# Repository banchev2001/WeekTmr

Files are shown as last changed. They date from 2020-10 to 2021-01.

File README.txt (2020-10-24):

 Files description:
 ================================================================================
 * DS3231_datasheet.pdf - Data sheet of DS3231 RTCC
 * DS3231_Library_Documentation.pdf - Library documentation by Henning Karlsen
 * RTC_DS3231_LCD_Test.ino - Main source code of the project - using Arduino IDE
 * /libraries/DS3231 contain Henning Karlsen free library with examples
 * /libraries/WeekTimerLibrary/ contain Stoian Banchev library for WeekTimer object
 * /Board/WeekTmr contain cidKad project of the board and schematic 
 
 Board: Arduino nano
 
 Project Conception:
 ================================================================================
 The board have two timers with three layers. Each timer have output. Timer1 
 drives Output-1 (pin 14), Timer2 drives Output-2 (pin 15). Every lyer of timers 
 are connected in "OR" logic to output. Every layer have three settings "On time", "Off time" and 
 Day of week scheme.
 
 Logic Diagram:
 ================================================================================
 
 Timer1, Layer1 ---|
 Timer1, Layer2 ---|-|OR|-Output1 (pin 14)
 Timer1, Layer3 ---|
 
 Timer2, Layer1 ---|
 Timer2, Layer2 ---|-|OR|-Output2 (pin 15)
 Timer2, Layer3 ---|

 Timer settings:
 ==================================================================================
 Days: Days in week in wich timer work,  contain seven fields for every day of week.
 On Time: Hour and minutes of the day that timer start.
 Off Time: Hour and minutes of the day that timer stop.

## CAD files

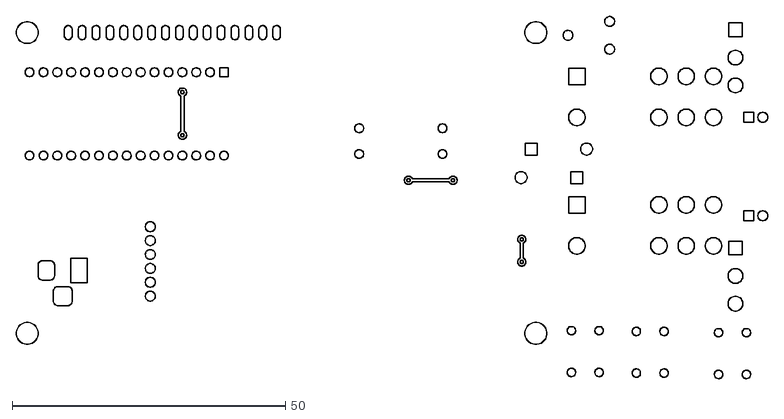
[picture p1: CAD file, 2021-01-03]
Board/WeekTmr/WeekTmr-F_Cu.dxf
137.4 x 66.2

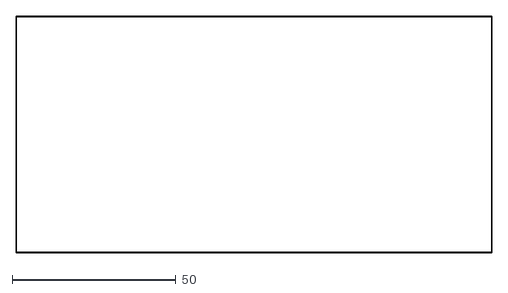
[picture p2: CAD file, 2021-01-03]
Board/WeekTmr/WeekTmr-Edge_Cuts.dxf
145.1 x 72.1

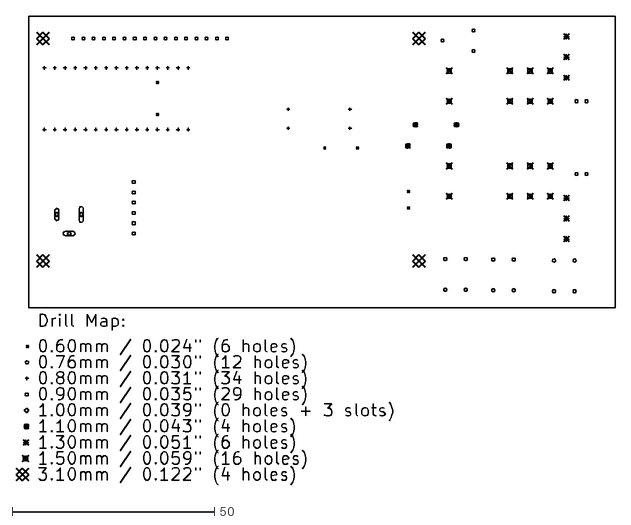
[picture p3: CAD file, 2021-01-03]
Board/WeekTmr/WeekTmr-PTH-drl_map.dxf
148.1 x 115.8

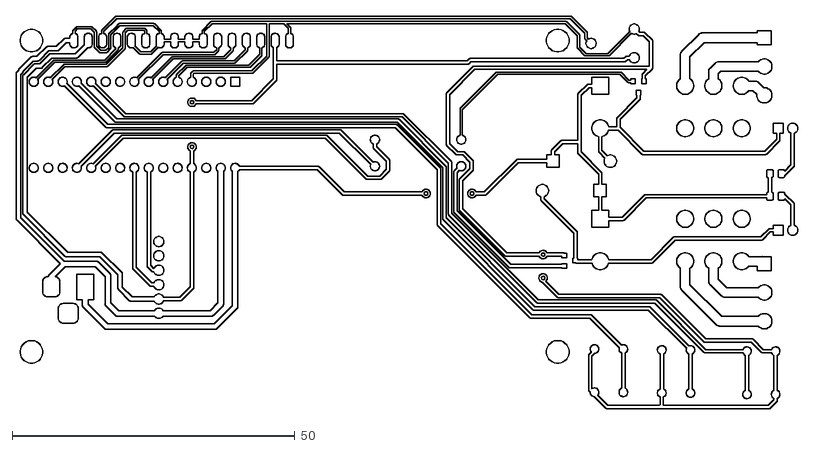
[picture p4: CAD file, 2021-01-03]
Board/WeekTmr/WeekTmr-B_Cu.dxf
138.1 x 69.3

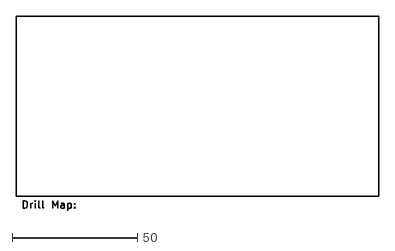
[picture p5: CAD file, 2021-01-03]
Board/WeekTmr/WeekTmr-NPTH-drl_map.dxf
145.0 x 77.7

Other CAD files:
Board/WeekTmr/WeekTmr-B_Mask.dxf
Board/WeekTmr/WeekTmr-B_Paste.dxf
Board/WeekTmr/WeekTmr-B_SilkS.dxf
Board/WeekTmr/WeekTmr-F_Mask.dxf
Board/WeekTmr/WeekTmr-F_Paste.dxf
Board/WeekTmr/WeekTmr-F_SilkS.dxf

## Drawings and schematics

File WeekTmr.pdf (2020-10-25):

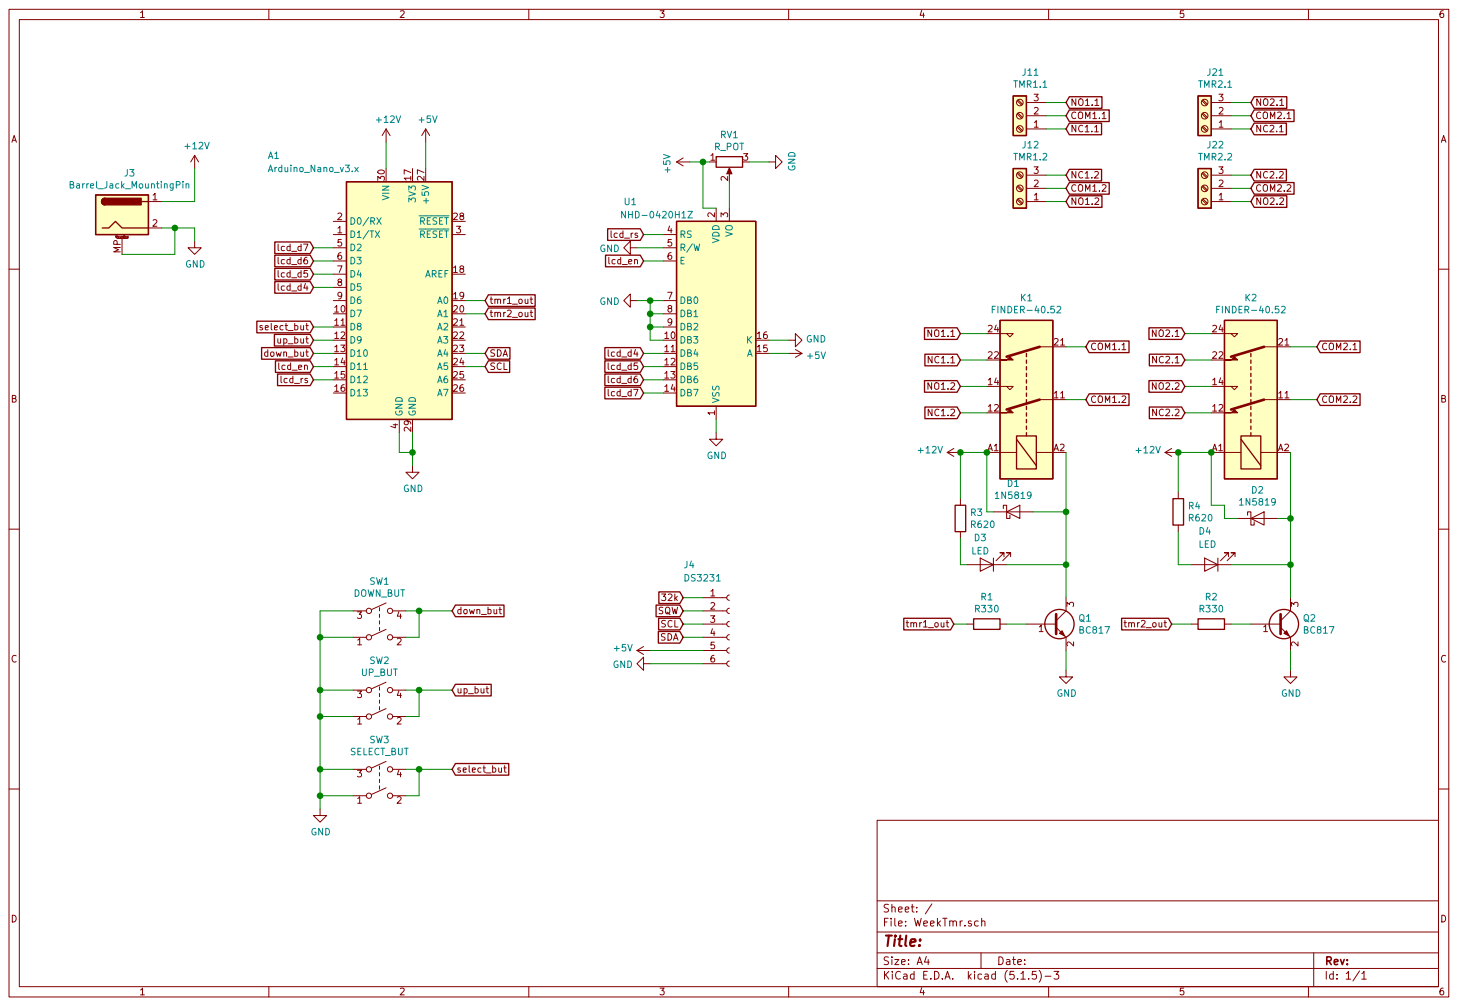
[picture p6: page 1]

Id: 1/1 Title: File: WeekTmr.sch Sheet: /

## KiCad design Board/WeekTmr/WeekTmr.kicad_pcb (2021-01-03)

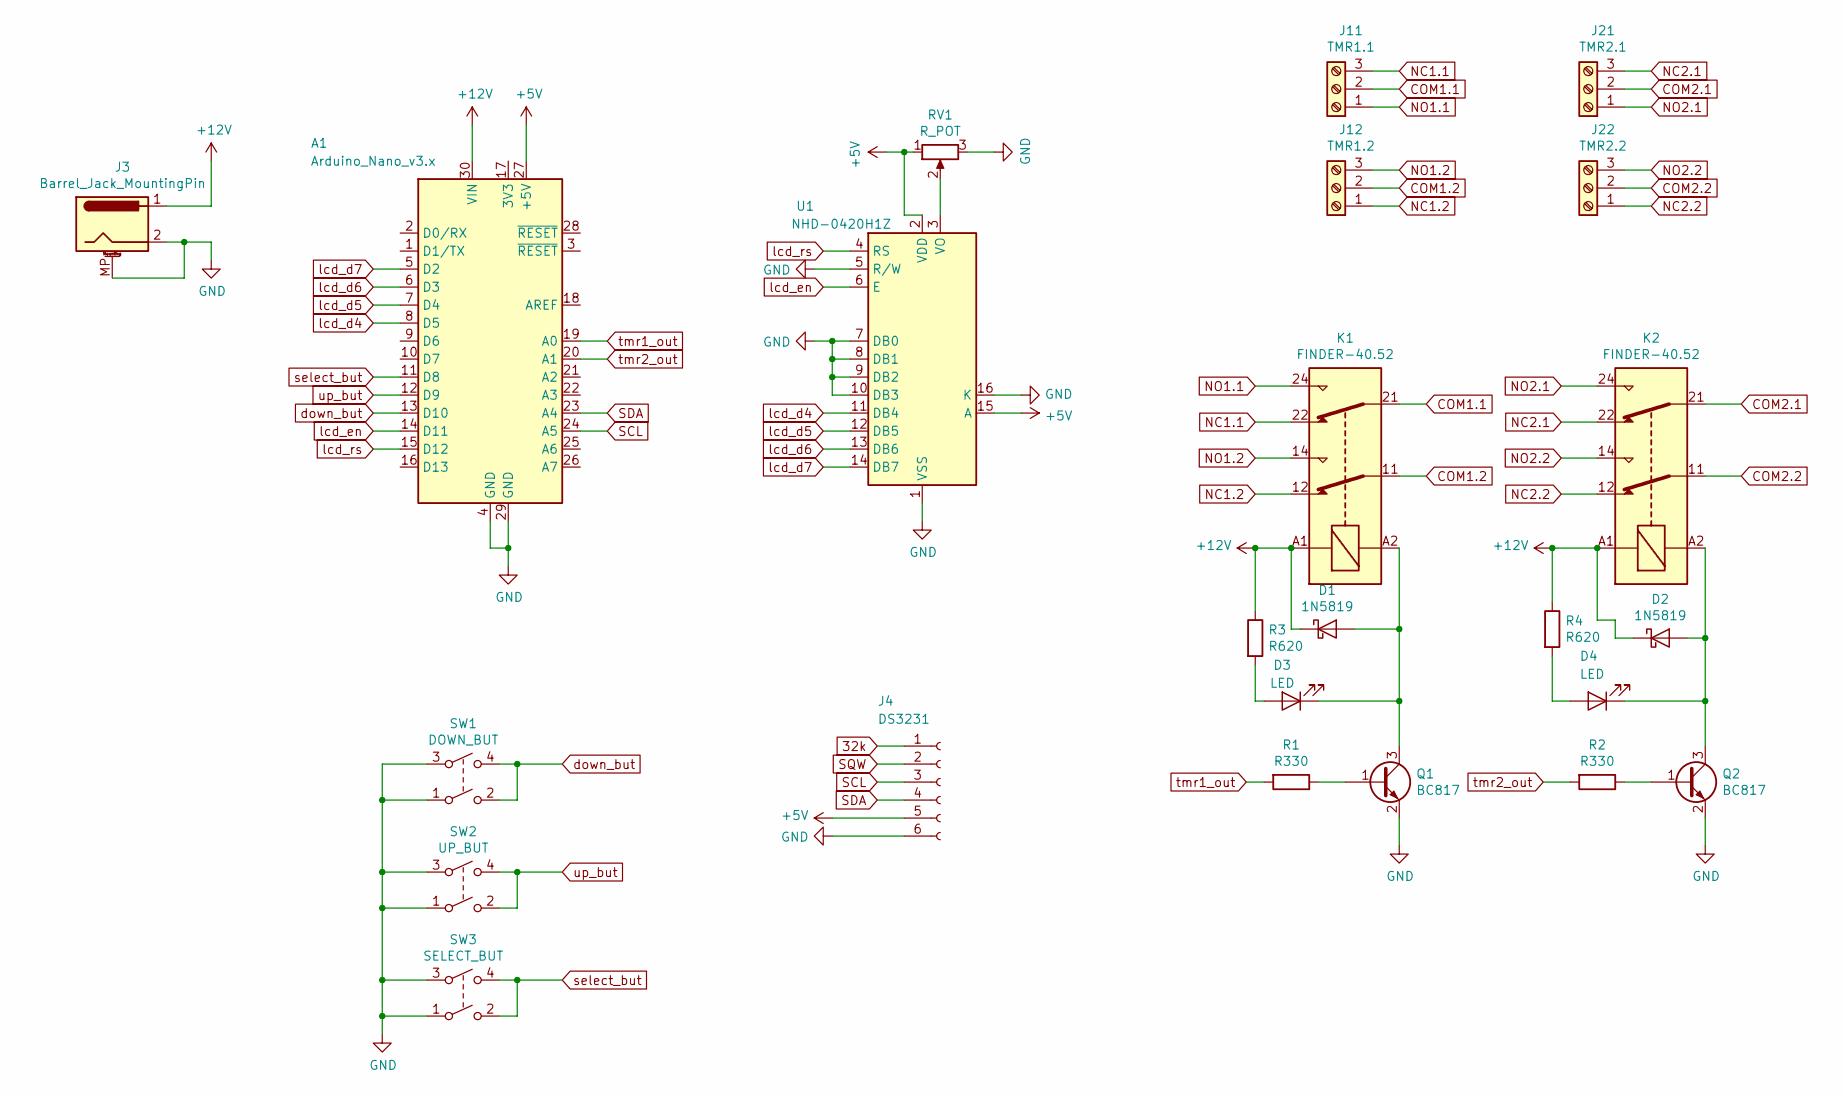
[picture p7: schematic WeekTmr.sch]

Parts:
A1: Arduino_Nano_v3.x; Arduino_Nano_direct_Slot
D1, D2: 1N5819; D_DO-41_SOD81_P10.16mm_Horizontal
D3, D4: LED; LED_D5.0mm_Clear
J3: Barrel_Jack_MountingPin; BarrelJack_Horizontal_comet
J4: DS3231; DS3231_RTC_Module
J11: TMR1.1; COMET_2EDGR-5.08-14-00AH
J12: TMR1.2; COMET_2EDGR-5.08-14-00AH
J21: TMR2.1; COMET_2EDGR-5.08-14-00AH
J22: TMR2.2; COMET_2EDGR-5.08-14-00AH
K1, K2: FINDER-40.52; Relay_DPDT_Finder_40.52
Q1, Q2: BC817; SOT-23
R1, R2: R330; R_Axial_DIN0207_L6.3mm_D2.5mm_P15.24mm_Horizontal
R3, R4: R620; R_0805_2012Metric_Pad1.15x1.40mm_HandSolder
RV1: R_POT; Pot_custom
SW1: DOWN_BUT; SW_Button
SW2: UP_BUT; SW_Button
SW3: SELECT_BUT; SW_Button
U1: NHD-0420H1Z; LCD_4x20_Stoian

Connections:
32k: J4.1
+5V: A1.27 (+5V), J4.5, RV1.1, U1.2 (VDD), U1.15 (A)
+12V: A1.30 (VIN), D1.1 (K), D2.1 (K), J3.1, K1.A1, K2.A1, R3.1, R4.1
COM1.1: J11.2, K1.21
COM1.2: J12.2, K1.11
COM2.1: J21.2, K2.21
COM2.2: J22.2, K2.11
GND: A1.4 (GND), A1.29 (GND), J3.2, J3.MP (MountPin), J4.6, Q1.2 (E), Q2.2 (E), RV1.3, SW1.1, SW1.3, SW2.1, SW2.3, SW3.1, SW3.3, U1.1 (VSS), U1.5 (R/W), U1.7 (DB0), U1.8 (DB1), U1.9 (DB2), U1.10 (DB3), U1.16 (K)
NC1.1: J11.3, K1.22
NC1.2: J12.1, K1.12
NC2.1: J21.3, K2.22
NC2.2: J22.1, K2.12
NO1.1: J11.1, K1.24
NO1.2: J12.3, K1.14
NO2.1: J21.1, K2.24
NO2.2: J22.3, K2.14
unnamed: D1.2 (A), D3.1 (K), K1.A2, Q1.3 (C)
unnamed: D2.2 (A), D4.1 (K), K2.A2, Q2.3 (C)
unnamed: D3.2 (A), R3.2
unnamed: D4.2 (A), R4.2
unnamed: Q1.1 (B), R1.1
unnamed: Q2.1 (B), R2.1
unnamed: RV1.2, U1.3 (VO)
SCL: A1.24 (A5), J4.3
SDA: A1.23 (A4), J4.4
SQW: J4.2
down_but: A1.13 (D10), SW1.2, SW1.4
lcd_d4: A1.8 (D5), U1.11 (DB4)
lcd_d5: A1.7 (D4), U1.12 (DB5)
lcd_d6: A1.6 (D3), U1.13 (DB6)
lcd_d7: A1.5 (D2), U1.14 (DB7)
lcd_en: A1.14 (D11), U1.6 (E)
lcd_rs: A1.15 (D12), U1.4 (RS)
select_but: A1.11 (D8), SW3.2, SW3.4
tmr1_out: A1.19 (A0), R1.2
tmr2_out: A1.20 (A1), R2.2
up_but: A1.12 (D9), SW2.2, SW2.4

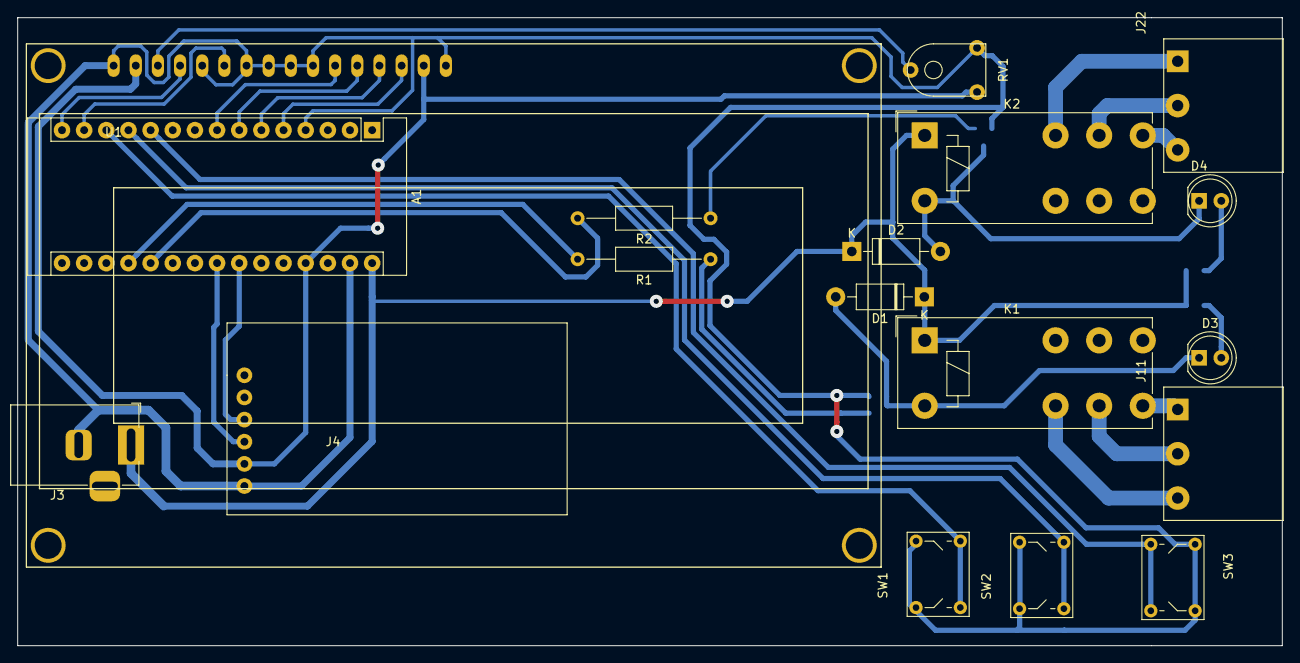
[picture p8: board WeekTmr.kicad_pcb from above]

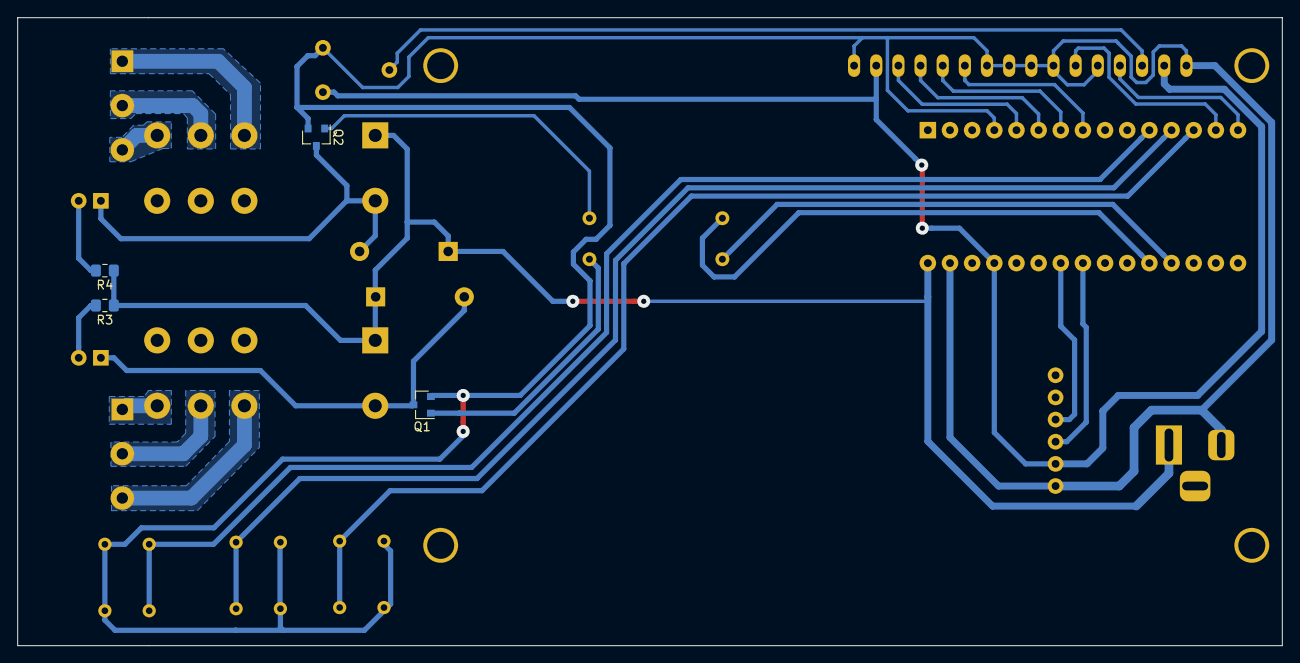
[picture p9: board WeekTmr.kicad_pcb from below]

Board: 2 copper layers, 145.0 x 72.0 mm, 22 parts (4 on the bottom side), 29 nets.

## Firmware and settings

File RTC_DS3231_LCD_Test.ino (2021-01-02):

/*

Start Date: 29.08.2020
Source Web: https://howtomechatronics.com/tutorials/arduino/arduino-ds3231-real-time-clock-tutorial
DS3231 Library Document Web: http://www.rinkydinkelectronics.com/library.php?id=73

Author: Stoian Banchev
Web: https://github.com/banchev2001/WeekTmr
Is based on Siemens Logo conception for Week timer function.
*/

/*
* Arduino DS3231 Real Time Clock Module Tutorial
* Crated by Dejan Nedelkovski,
* www.HowToMechatronics.com
* DS3231 Library made by Henning Karlsen which can be found and downloaded from his website, www.rinkydinkelectronics.com.
*/
#include <Arduino.h>
#include <DS3231.h>
#include <LiquidCrystal.h> // includes the LiquidCrystal Library 
#include <WeekTimer.h> //My custom library for week timer functions
#include <EEPROM.h> 

//Define custom name of Buttons
#define DOWN_BUTTON 10
#define UP_BUTTON 9
#define SELECT_BUTTON 8

//Define custom name of Outputs
#define TMR1_OUT 14 //A0 pin
#define TMR2_OUT 15 //A1 pin

//Define constant for logic control
#define ON 1
#define OFF 0

/***********Control First Initialization!!!********************/
//#define FIRST_INI //Uncoment for first load to Arduino board and then coment back!
/***********Control First Initialization!!!********************/

/*************************Inicialazing Objects ************************/
  Time arduTime; //Create object arduTime wich save time in arduino
  DS3231  dsTime(SDA, SCL); //Create object wich 
  //Parameters: (rs, enable, d4, d5, d6, d7) 
  LiquidCrystal lcd(12, 11, 5, 4, 3, 2); // Creates an LCD object. 
  WeekTimer WT[3][4];
 /*********************************************************************/
  

  /****************** Global Variables ********************************/
  //
  enum CursAddr {Home = 0, HOUR_ADR, MINUTES_ADR, SECONDS_ADR, 
                 DAY_ADR, MONTH_ADR, YEAR_ADR, DOW_ADR, MON_ADR,
                 TUE_ADR, WED_ADR, THU_ADR, FRI_ADR, SAT_ADR, SUN_ADR,
                 ONH_ADR, ONM_ADR, OFFH_ADR, OFFM_ADR} CursPlace ;
  //               
  enum Display {MAIN_DISP = 0, TMR1_L1, TMR1_L2, TMR1_L3, TMR2_L1, TMR2_L2, 
                                            TMR2_L3} DisplayPage ;
  
  /********************************************************************/
  void StartDisplay(void);
  void TmrUpBut(uint8_t Timer, uint8_t TimerLyer); //Control Prssing up button on timer display page
  void TmrDowBut(uint8_t Timer, uint8_t TimerLyer);//Control Prssing down button on timer display page
  void WeekT_Display(uint8_t Timer, uint8_t TimerLyer); //Show Timer layer display 
  void MainDisplay();//Show main display
  void SaveTimer(int8_t Tmr, int8_t Lyr); // Save Timers Layers settings in EEPROM
  void LoadTimer(int8_t Tmr, int8_t Lyr); // Load Timers Layers settings from EEPROM
  void SaveDispMsg(int8_t Tmr, int8_t Lyr); //Display Masage after save in EEPROM

void setup() { 

  /************************Initial Timers**********************/
    #ifdef FIRST_INI //Part of code for first initialisation of timers
                    //If not difained is not executed 
      
      WT[0][0].SetWeekPlanStr("MTWTFSS");//TMR1 lyer 1 Settings
      WT[0][0].SetOnTime(18,30);
      WT[0][0].SetOffTime(22,00);
      
      WT[0][1].SetWeekPlanStr("-----SS");//TMR1 lyer 2 Settings 
      WT[0][1].SetOnTime(12,30);
      WT[0][1].SetOffTime(14,35);
    
      WT[0][2].SetWeekPlanStr("-------");//TMR1 lyer 3 Settings
      WT[0][2].SetOnTime(12,30);
      WT[0][2].SetOffTime(14,35);
    
      WT[1][0].SetWeekPlanStr("MTWTFSS");//TMR2 lyer 1 Settings
      WT[1][0].SetOnTime(20,00);
      WT[1][0].SetOffTime(22,30);
      
      WT[1][1].SetWeekPlanStr("-------");//TMR2 lyer 2 Settings
      WT[1][1].SetOnTime(11,00);
      WT[1][1].SetOffTime(12,45);
    
      WT[1][2].SetWeekPlanStr("-------");//TMR2 lyer 3 Settings
      WT[1][2].SetOnTime(20,00);
      WT[1][2].SetOffTime(22,30);
    //Write all settings to EEPROM
    SaveTimer(1,1); SaveTimer(1,2); SaveTimer(1,3); SaveTimer(2,1); SaveTimer(2,2); SaveTimer(2,3);
    #endif
     
    //Loading all Settings from EEPROM    
    LoadTimer(1,1); LoadTimer(1,2); LoadTimer(1,3); LoadTimer(2,1); LoadTimer(2,2); LoadTimer(2,3);
    
  /********************** EOF Initial Timers ******************/

  /********************** Custom Charter **********************/
  //Here is creating custom charter for FrancTex logo

 
  

  /************************************************************/
   
  CursPlace = Home; //Set Cursor in home position
  DisplayPage = MAIN_DISP; //Set display to home
  
  /*****Config Pins and define custom names of pins *****/
  //Inputs
  pinMode(DOWN_BUTTON, INPUT_PULLUP);
  pinMode(UP_BUTTON, INPUT_PULLUP);
  pinMode(SELECT_BUTTON, INPUT_PULLUP);
  
  //Outputs
  pinMode(TMR1_OUT, OUTPUT);
  pinMode(TMR2_OUT, OUTPUT);
  /******************************************************/
  
  dsTime.begin(); // Initialize the dsTime object
  lcd.begin(20,4); // Initializes the interface to the LCD screen, and specifies the dimensions (width and height) of the display } 

  StartDisplay(); //Show start display

}


void loop() { 
  
  //SELECT BUTTON REACTION
  //===========================================================================================================
    if (!digitalRead(SELECT_BUTTON)){

      if(DisplayPage == MAIN_DISP){ 
          CursPlace = static_cast<CursAddr>(CursPlace + 1); //Here read more about cast operator
          while(!digitalRead(SELECT_BUTTON));
           
            if(CursPlace > DOW_ADR){ //Write all arduTime Data and send it to DS3231
                CursPlace = Home;
                dsTime.setTime(arduTime.hour, arduTime.min, arduTime.sec); 
                dsTime.setDate(arduTime.date, arduTime.mon, arduTime.year);
                dsTime.setDOW();  //This way automaticly correct Day of week            
            }
      }
      
      else{ 
          if(CursPlace < DOW_ADR) CursPlace = DOW_ADR;
          CursPlace = static_cast<CursAddr>(CursPlace + 1); 
          
          while(!digitalRead(SELECT_BUTTON));
            
            if(CursPlace > OFFM_ADR){ //Write Configured Settings in EEPROM
                if(DisplayPage == TMR1_L1){
                  SaveTimer(1,1);
                  SaveDispMsg(1,1);
                  WeekT_Display(1,1);
                }
                if(DisplayPage == TMR1_L2){
                  SaveTimer(1,2);
                  SaveDispMsg(1,2);
                  WeekT_Display(1,2);
                }
                if(DisplayPage == TMR1_L3){
                  SaveTimer(1,3);
                  SaveDispMsg(1,3);
                  WeekT_Display(1,3); 
                }
                if(DisplayPage == TMR2_L1){
                  SaveTimer(2,1);
                  SaveDispMsg(2,1);
                  WeekT_Display(2,1); 
                }
                if(DisplayPage == TMR2_L2){
                  SaveTimer(2,2);
                  SaveDispMsg(2,2);
                  WeekT_Display(2,2); 
                }
                if(DisplayPage == TMR2_L3){
                  SaveTimer(2,3);
                  SaveDispMsg(2,3);
                  WeekT_Display(2,3); 
                }    
                CursPlace = Home;
            }
      }
  }

  //UP BUTTON REACTION
  //===========================================================================================================
  if (!digitalRead(UP_BUTTON)){

      if(CursPlace == Home){
        if(DisplayPage == MAIN_DISP) DisplayPage = TMR2_L3;
        else DisplayPage = static_cast<Display>(DisplayPage - 1);
        lcd.clear();
        
      }
         
      if (DisplayPage == MAIN_DISP) {
             
         if(CursPlace == YEAR_ADR){//Curssor is pointed on the Month
         arduTime.year++;//Incrase day of month
         if(arduTime.year > 2099)arduTime.year = 2000;
         }
         //-----------------------------------------------------
         if(CursPlace == MONTH_ADR){//Curssor is pointed on the Month
         arduTime.mon++;//Incrase day of month
         if(arduTime.mon > 12)arduTime.mon = 0; //HERE WE NEED MORE VERIFICATIONS!!!
         }
         //-----------------------------------------------------
         if(CursPlace == DAY_ADR){//Curssor is pointed on the Day
         arduTime.date++;//Incrase day of month
         if(arduTime.date > 31)arduTime.date = 0; //HERE WE NEED MORE VERIFICATIONS!!!
         }
         //-----------------------------------------------------
          if(CursPlace == HOUR_ADR){ //Curssor is pointed to Hour
          arduTime.hour++; //Incrase Hour
          if(arduTime.hour > 23)arduTime.hour = 0;//Check If Hour is reached 23 and turn back to 0 
         }
         //-----------------------------------------------------

         if(CursPlace == MINUTES_ADR){ //Curssor is pointed to Minutes
          arduTime.min++; //Incrase Minutes
          if(arduTime.min > 59)arduTime.min = 0;//Check If Minutes is reached 59 and turn back to 0 
         }
         //-----------------------------------------------------

         if(CursPlace == SECONDS_ADR){ //Curssor is pointed to Seconds
          arduTime.sec++; //Incrase Minutes
          if(arduTime.sec > 59)arduTime.sec = 0;//Check If Seconds is reached 59 and turn back to 0 
         }
         //-----------------------------------------------------
    
        if(CursPlace == DOW_ADR){ //Curssor is pointed to Day Of Week
          arduTime.dow++; //Incrase Day Of Week
          if(arduTime.dow > SUNDAY)arduTime.dow = MONDAY;//Check Day If is SunDay turn Back to Monday
          dsTime.setDOW(arduTime.dow);//Write to back to DS3231          
         }
         //-----------------------------------------------------

       while(!digitalRead(UP_BUTTON));
       MainDisplay();

      }
      if (DisplayPage == TMR1_L1) {
        TmrUpBut(1, 1);//Control Sub routine
        WeekT_Display(1,1);//Display Update subroutine
      }
      if (DisplayPage == TMR1_L2) {
        TmrUpBut(1, 2);//Control Sub routine
        WeekT_Display(1,2); 
      }
      if (DisplayPage == TMR1_L3) {
        TmrUpBut(1, 3);//Control Sub routine
        WeekT_Display(1,3); 
      }
      if (DisplayPage == TMR2_L1) {
        TmrUpBut(2, 1);//Control Sub routine
        WeekT_Display(2,1); 
      }
      if (DisplayPage == TMR2_L2) {
        TmrUpBut(2, 2);//Control Sub routine
        WeekT_Display(2,2); 
      }
      if (DisplayPage == TMR2_L3) {
        TmrUpBut(2, 3);//Control Sub routine
        WeekT_Display(2,3); 
      }
      while(!digitalRead(UP_BUTTON));
  }

  //DOWN BUTTON REACTION
  //===========================================================================================================
  if (!digitalRead(DOWN_BUTTON)){
     
     if(CursPlace == Home){
        DisplayPage = static_cast<Display>(DisplayPage + 1);  
        if(DisplayPage > TMR2_L3) DisplayPage = MAIN_DISP;
        lcd.clear();
      }
    if (DisplayPage == MAIN_DISP) {
      
         if(CursPlace == YEAR_ADR){ //Curssor is pointed to Year
          if(arduTime.year == 2000) arduTime.year = 2099;//Check If Year is reached 2000 and turn back to 2099 
          else arduTime.year--;//Decrase Month
         }
         //-----------------------------------------------------
         if(CursPlace == MONTH_ADR){ //Curssor is pointed to Month
          if(!arduTime.mon) arduTime.mon = 12;//Check If Month is reached 0 and turn back to 12 
          else arduTime.mon--;//Decrase Month
         }//HERE WE NEED MORE VERIFICATIONS!!!
         //-----------------------------------------------------
         if(CursPlace == DAY_ADR){ //Curssor is pointed to Day
          if(!arduTime.date) arduTime.date = 31;//Check If Day is reached 0 and turn back to 31 
          else arduTime.date--;//Decrase Day
         }//HERE WE NEED MORE VERIFICATIONS!!!
         //-----------------------------------------------------
         if(CursPlace == HOUR_ADR){ //Curssor is pointed to Hour
          if(!arduTime.hour) arduTime.hour = 23;//Check If Hour is reached 0 and turn back to 23 
          else arduTime.hour--;//Decrase Hour
         }
         //-----------------------------------------------------
         if(CursPlace == MINUTES_ADR){ //Curssor is pointed to Minutes
          if(!arduTime.min)arduTime.min = 59;//Check If Minutes is reached 0 and turn back to 59 
          else arduTime.min--; //Decrase Minutes            
         }
         //-----------------------------------------------------
         if(CursPlace == SECONDS_ADR){ //Curssor is pointed to Seconds
          if(!arduTime.sec)arduTime.sec = 59;//Check If Seconds is reached 0 and turn back to 59 
          else arduTime.sec--; //Decrase Seconds      
         }
         //-----------------------------------------------------
         if(CursPlace == DOW_ADR){ //Curssor is pointed to Day Of Week
          arduTime.dow--; //Decrase Day Of Week
          if(arduTime.dow < MONDAY)arduTime.dow = SUNDAY; //Check Day If is Monday turn back to SunDay 
          dsTime.setDOW(arduTime.dow);//Write to back to DS3231          
         }
         //------------------------------------------------------
         
       while(!digitalRead(DOWN_BUTTON)); //Wait for relase the button
       delay(20);//Debaunce relase
       MainDisplay();
     }
    if (DisplayPage == TMR1_L1) {
      TmrDowBut(1,1);
      WeekT_Display(1,1); 
    }
    if (DisplayPage == TMR1_L2) {
      TmrDowBut(1,2);
      WeekT_Display(1,2); 
    }
    if (DisplayPage == TMR1_L3) {
      TmrDowBut(1,3);
      WeekT_Display(1,3); 
    }
    if (DisplayPage == TMR2_L1) {
      TmrDowBut(2,1);
      WeekT_Display(2,1); 
    }
    if (DisplayPage == TMR2_L2) {
      TmrDowBut(2,2);
      WeekT_Display(2,2); 
    }
    if (DisplayPage == TMR2_L3) {
      TmrDowBut(2,3);
      WeekT_Display(2,3); 
    }
    while(!digitalRead(DOWN_BUTTON));
   }
 
  
      
       //Turn Off curssor when rotate all parameters
        if(CursPlace == Home){
        lcd.noBlink();
        if (DisplayPage == MAIN_DISP) MainDisplay(); //Update Main display  
       }
        else{
        lcd.blink();
       }
       
       //Place Curssor on the Time
       //--------------------------------------------
       if(CursPlace == HOUR_ADR)
        lcd.setCursor(7,0);
       if(CursPlace == MINUTES_ADR)
        lcd.setCursor(10,0);
       if(CursPlace == SECONDS_ADR)
        lcd.setCursor(13,0);
       //Place Curssor on the Date
       //--------------------------------------------
       if(CursPlace == DAY_ADR)
        lcd.setCursor(7,1);
       if(CursPlace == MONTH_ADR)
        lcd.setCursor(10,1);
       if(CursPlace == YEAR_ADR)
        lcd.setCursor(15,1);
       //Place Curssor on the Day Of Week
       //-------------------------------------------
       if(CursPlace == DOW_ADR)
        lcd.setCursor(6,2);
       //Place Curssor on the Monday
       //-------------------------------------------
       if(CursPlace == MON_ADR)
        lcd.setCursor(6,1);
       //Place Curssor on the Tuesday
       //-------------------------------------------
       if(CursPlace == TUE_ADR)
        lcd.setCursor(7,1);
       //Place Curssor on the Wednesday
       //-------------------------------------------
       if(CursPlace == WED_ADR)
        lcd.setCursor(8,1);
       //Place Curssor on the Thursday
       //-------------------------------------------
       if(CursPlace == THU_ADR)
        lcd.setCursor(9,1);
       //Place Curssor on the Friday
       //-------------------------------------------
       if(CursPlace == FRI_ADR)
        lcd.setCursor(10,1);
       //Place Curssor on the Saturday
       //-------------------------------------------
       if(CursPlace == SAT_ADR)
        lcd.setCursor(11,1);
       //Place Curssor on the Saturday
       //-------------------------------------------
       if(CursPlace == SUN_ADR)
        lcd.setCursor(12,1);
       //Place Curssor on the On Hour parameter
       //-------------------------------------------
       if(CursPlace == ONH_ADR)
        lcd.setCursor(6,2);
       //Place Curssor on the On Minutes parameter
       //-------------------------------------------
       if(CursPlace == ONM_ADR)
        lcd.setCursor(9,2);
       //Place Curssor on the Off Hour parameter
       //-------------------------------------------
       if(CursPlace == OFFH_ADR)
        lcd.setCursor(6,3);
       //Place Curssor on the Off Minutes parameter
       //-------------------------------------------
       if(CursPlace == OFFM_ADR)
        lcd.setCursor(9,3);
       
   //Here place code for checking some of timers Out
   //==================================================================
   if(CursPlace == Home)arduTime = dsTime.getTime(); //Get current time from DS3231
   
   if(WT[0][0].Check(arduTime.dow, arduTime.hour, arduTime.min)|| //OR TMR1 L1
      WT[0][1].Check(arduTime.dow, arduTime.hour, arduTime.min)|| //OR TMR1 L2
      WT[0][2].Check(arduTime.dow, arduTime.hour, arduTime.min))  //OR TMR1 L3
   
            digitalWrite(TMR1_OUT, HIGH); //Set ON output 1 
    else
            digitalWrite(TMR1_OUT, LOW); //Set OFF output 1

    if(WT[1][0].Check(arduTime.dow, arduTime.hour, arduTime.min)||  //OR TMR2 L1
       WT[1][1].Check(arduTime.dow, arduTime.hour, arduTime.min)||  //OR TMR2 L2
       WT[1][2].Check(arduTime.dow, arduTime.hour, arduTime.min))   //OR TMR2 L3
   
            digitalWrite(TMR2_OUT, HIGH); //Set ON output 2 
    else
            digitalWrite(TMR2_OUT, LOW); //Set OFF output 2
   
   //==================================================================
   //End of code checking timers
   
   
 
   delay(70); //debounce delay for buttons!
   
}//End of Main Loop bracket
/*************************************************************************************/
/*                                 END OF MAIN LOOP                                  */
/*************************************************************************************/



/*************************************************************************************/
/*                                 Custom Function START                             */
/*************************************************************************************/
void TmrUpBut(uint8_t Timer, uint8_t TimerLyer){
  if(CursPlace == MON_ADR)
    WT[Timer-1][TimerLyer-1].EnableWD(MONDAY);       
  if(CursPlace==TUE_ADR)
    WT[Timer-1][TimerLyer-1].EnableWD(TUESDAY);
  if(CursPlace==WED_ADR)
    WT[Timer-1][TimerLyer-1].EnableWD(WEDNESDAY);
  if(CursPlace==THU_ADR)
    WT[Timer-1][TimerLyer-1].EnableWD(THURSDAY);
  if(CursPlace==FRI_ADR)
    WT[Timer-1][TimerLyer-1].EnableWD(FRIDAY);
  if(CursPlace==SAT_ADR)
    WT[Timer-1][TimerLyer-1].EnableWD(SATURDAY);
  if(CursPlace==SUN_ADR)
    WT[Timer-1][TimerLyer-1].EnableWD(SUNDAY);
 
  if(CursPlace==ONH_ADR){
    if(WT[Timer-1][TimerLyer-1].OnHour < 23) WT[Timer-1][TimerLyer-1].OnHour++;
    else WT[Timer-1][TimerLyer-1].OnHour = 0;
    WT[Timer-1][TimerLyer-1].ValOffTime();
  }
  if(CursPlace==ONM_ADR){
    if(WT[Timer-1][TimerLyer-1].OnMinutes < 59) WT[Timer-1][TimerLyer-1].OnMinutes++;
    else WT[Timer-1][TimerLyer-1].OnMinutes = 0;
    WT[Timer-1][TimerLyer-1].ValOffTime();
  }
  if(CursPlace==OFFH_ADR){
    if(WT[Timer-1][TimerLyer-1].OffHour < 23) WT[Timer-1][TimerLyer-1].OffHour++;
    else WT[Timer-1][TimerLyer-1].OffHour = 0;
    WT[Timer-1][TimerLyer-1].ValOnTime();
  }
  if(CursPlace==OFFM_ADR){
    if(WT[Timer-1][TimerLyer-1].OffMinutes < 59) WT[Timer-1][TimerLyer-1].OffMinutes++;
    else WT[Timer-1][TimerLyer-1].OffMinutes = 0;
    WT[Timer-1][TimerLyer-1].ValOnTime();
  }
 }
void TmrDowBut(uint8_t Timer, uint8_t TimerLyer){
  
  if(CursPlace == MON_ADR)
    WT[Timer-1][TimerLyer-1].DisableWD(MONDAY);       
  if(CursPlace==TUE_ADR)
    WT[Timer-1][TimerLyer-1].DisableWD(TUESDAY);
  if(CursPlace==WED_ADR)
    WT[Timer-1][TimerLyer-1].DisableWD(WEDNESDAY);
  if(CursPlace==THU_ADR)
    WT[Timer-1][TimerLyer-1].DisableWD(THURSDAY);
  if(CursPlace==FRI_ADR)
    WT[Timer-1][TimerLyer-1].DisableWD(FRIDAY);
  if(CursPlace==SAT_ADR)
    WT[Timer-1][TimerLyer-1].DisableWD(SATURDAY);
  if(CursPlace==SUN_ADR)
    WT[Timer-1][TimerLyer-1].DisableWD(SUNDAY);
    
  if(CursPlace==ONH_ADR){ 
    if(!WT[Timer-1][TimerLyer-1].OnHour)  WT[Timer-1][TimerLyer-1].OnHour = 23; //If Hour = 0 -> Hour = 23
    else WT[Timer-1][TimerLyer-1].OnHour--; //
    WT[Timer-1][TimerLyer-1].ValOffTime();
  }
  if(CursPlace==ONM_ADR){
    if(!WT[Timer-1][TimerLyer-1].OnMinutes) WT[Timer-1][TimerLyer-1].OnMinutes = 59;
    else WT[Timer-1][TimerLyer-1].OnMinutes--;
    WT[Timer-1][TimerLyer-1].ValOffTime();
  }
  if(CursPlace==OFFH_ADR){
    if(!WT[Timer-1][TimerLyer-1].OffHour) WT[Timer-1][TimerLyer-1].OffHour = 23;
    else WT[Timer-1][TimerLyer-1].OffHour--;
    WT[Timer-1][TimerLyer-1].ValOnTime();
  }
  if(CursPlace == OFFM_ADR){
    if(!WT[Timer-1][TimerLyer-1].OffMinutes) WT[Timer-1][TimerLyer-1].OffMinutes = 59;
    else WT[Timer-1][TimerLyer-1].OffMinutes--;
    WT[Timer-1][TimerLyer-1].ValOnTime();
  }
  //Here validating OnTime
} 
void WeekT_Display(uint8_t Timer, uint8_t TimerLyer){
  lcd.noBlink();
  lcd.setCursor(0,0);
  lcd.print("Timer: ");
  lcd.print(Timer);
  lcd.print(" Lyer: ");
  lcd.print(TimerLyer);

  lcd.setCursor(0,1);
  lcd.print("Days: ");
  lcd.print(WT[Timer-1][TimerLyer-1].GetWeekPlanStr());

  lcd.setCursor(0,2);
  lcd.print("On:  ");
  if(WT[Timer-1][TimerLyer-1].OnHour<10)
  lcd.print("0");
  lcd.print(WT[Timer-1][TimerLyer-1].OnHour, DEC);
  lcd.print(":");
  if(WT[Timer-1][TimerLyer-1].OnMinutes<10)
  lcd.print("0");
  lcd.print(WT[Timer-1][TimerLyer-1].OnMinutes, DEC);
  
  lcd.setCursor(0,3);
  lcd.print("Off: ");
  if(WT[Timer-1][TimerLyer-1].OffHour<10)
  lcd.print("0");
  lcd.print(WT[Timer-1][TimerLyer-1].OffHour, DEC);
  lcd.print(":");
  if(WT[Timer-1][TimerLyer-1].OffMinutes<10)
  lcd.print("0");
  lcd.print(WT[Timer-1][TimerLyer-1].OffMinutes, DEC);
  
}
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

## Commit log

2020-10-11 First Official Commit of Week Timer Arduino Project Signed-off-by: banchev2001 <banchev2001@abv.bg>
2020-10-24 Board update
    [WeekTmr.kicad_pcb, WeekTmr.sch]
2020-10-24 update schematic
    [WeekTmr.sch]
2020-10-24 pcb update
    [WeekTmr.sch]
2020-10-25 schem and board update
    [WeekTmr.kicad_pcb, WeekTmr.sch]
